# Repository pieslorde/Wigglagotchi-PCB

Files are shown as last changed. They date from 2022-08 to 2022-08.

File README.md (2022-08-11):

# Wigglagotchi-PCB
This repository contains the Altium Designer AD22 source files and generated Gerber, NC drill, and
documentation files for PCB of the Wigglagotchi. The enclosure for the device is maintained in
[Wigglagotchi-Mechanical](https://github.com/pieslorde/Wigglagotchi-Mechanical). The Wigglagotchi
is an open-source handheld gaming device with three buttons, a screen, an IMU, a buzzer, and an
IrDA transceiver to communicate with other Wigglagotchis.

The namesake of the Wigglagotchi is the Twitch streamer [Keffals](https://wikipedia.org/wiki/Keffals).
A frequent feature of her community is an [animated chibi-style version of herself
dancing](https://twitter.com/keffals/status/1509562415096213510), or wiggling. Chatters who use the emote are referred
to as "Wigglers", and the Wigglagotchi was designed to support virtual Wiggler pets for the user.

A document containing 3D renders of the assembled PCB, a BOM, and the schematic is
[included here](https://github.com/pieslorde/Wigglagotchi-PCB/blob/main/Project%20Outputs%20for%20Wigglagotchi/Documentation.PDF).

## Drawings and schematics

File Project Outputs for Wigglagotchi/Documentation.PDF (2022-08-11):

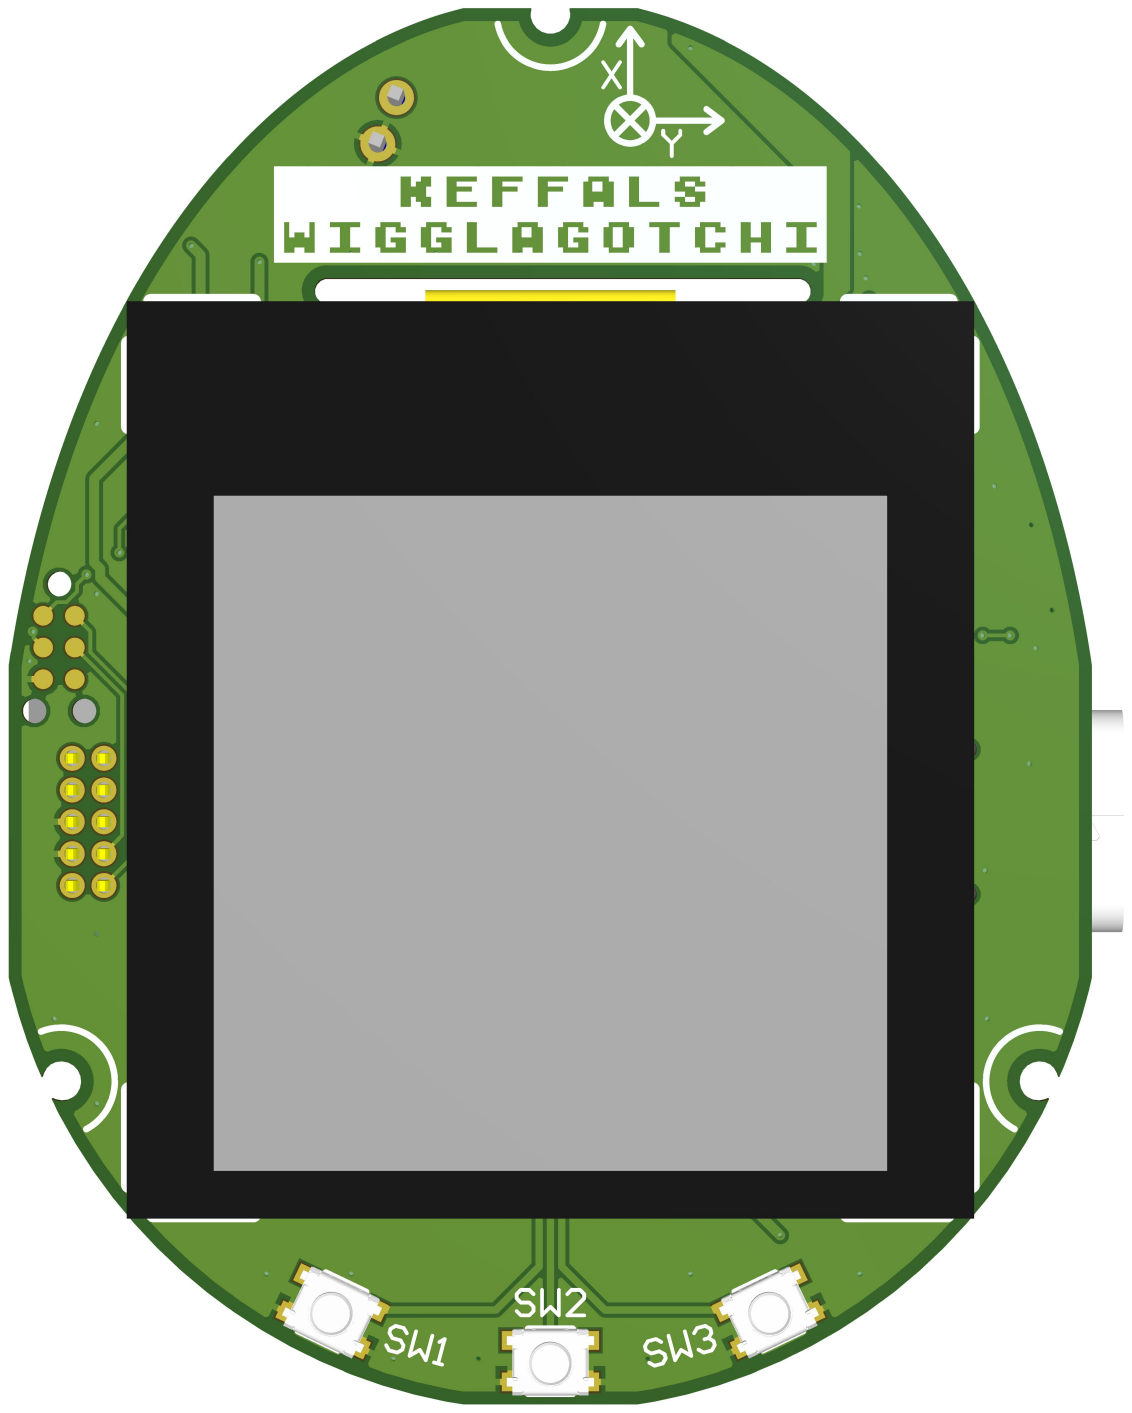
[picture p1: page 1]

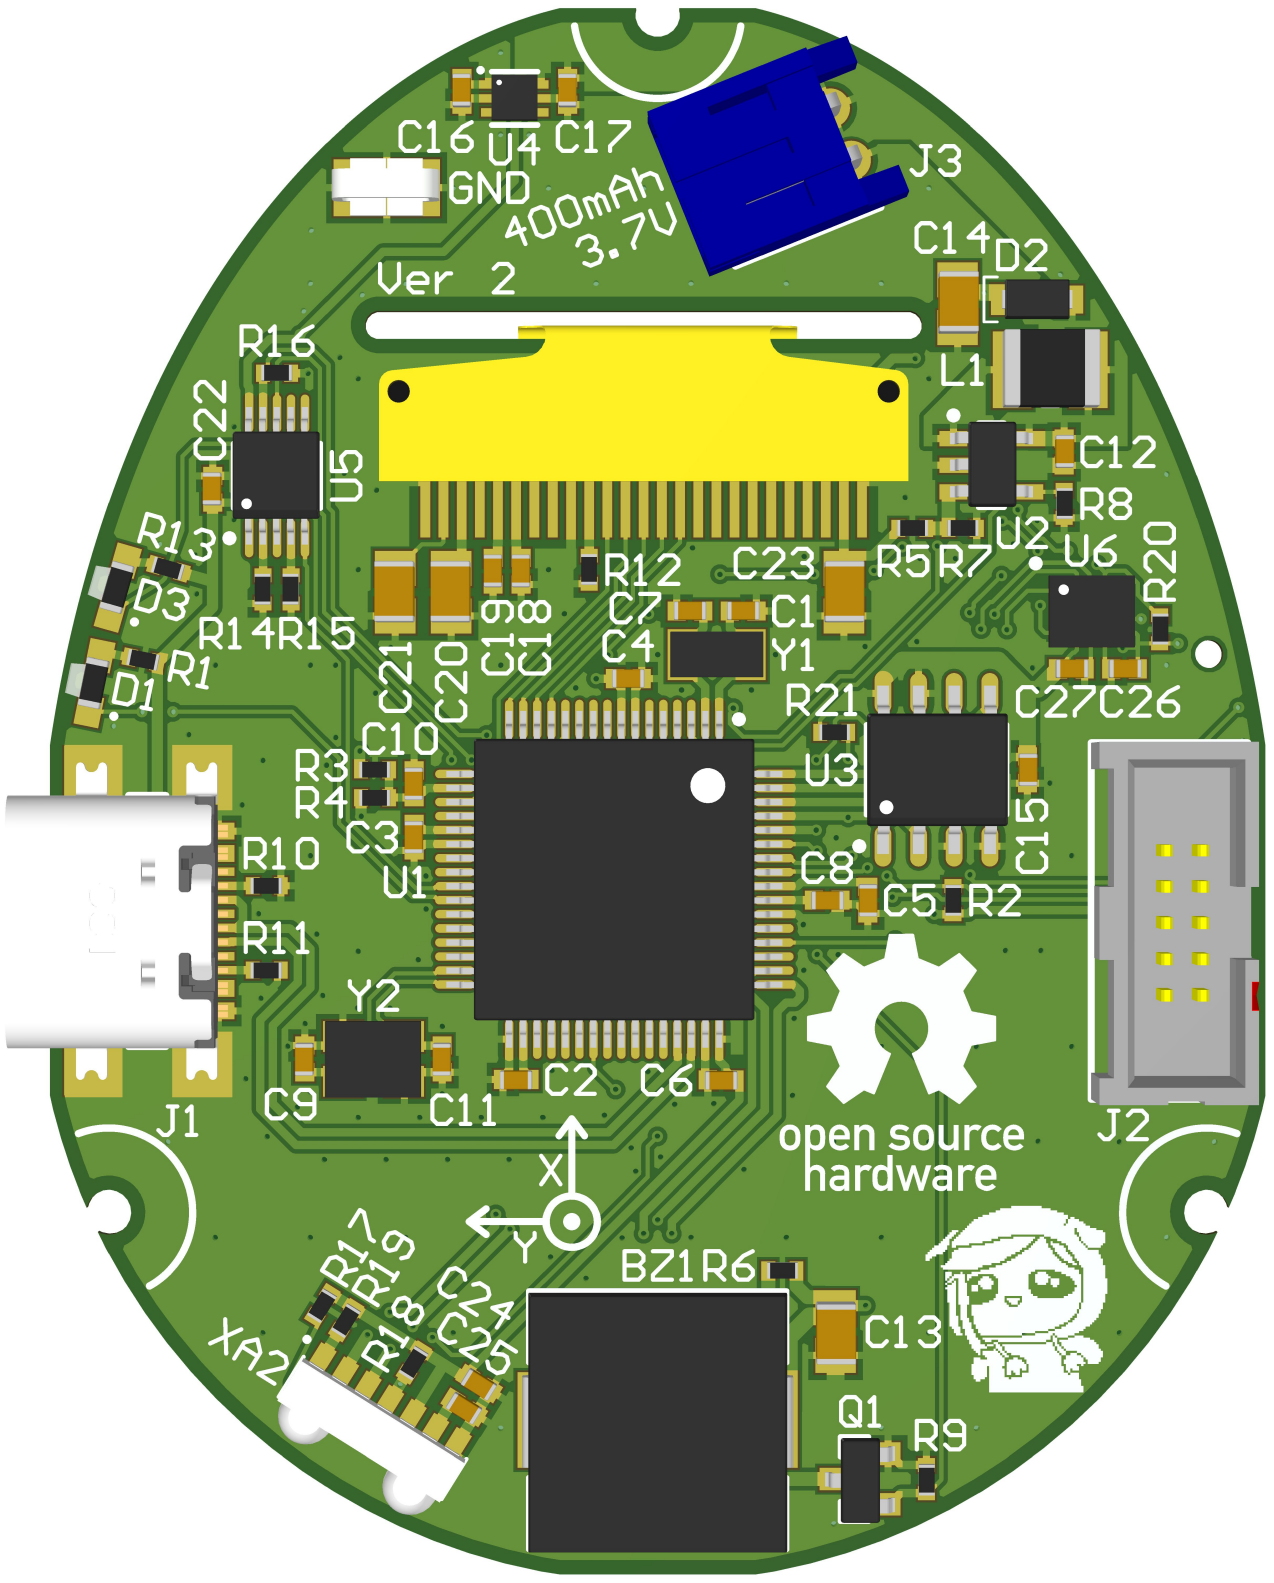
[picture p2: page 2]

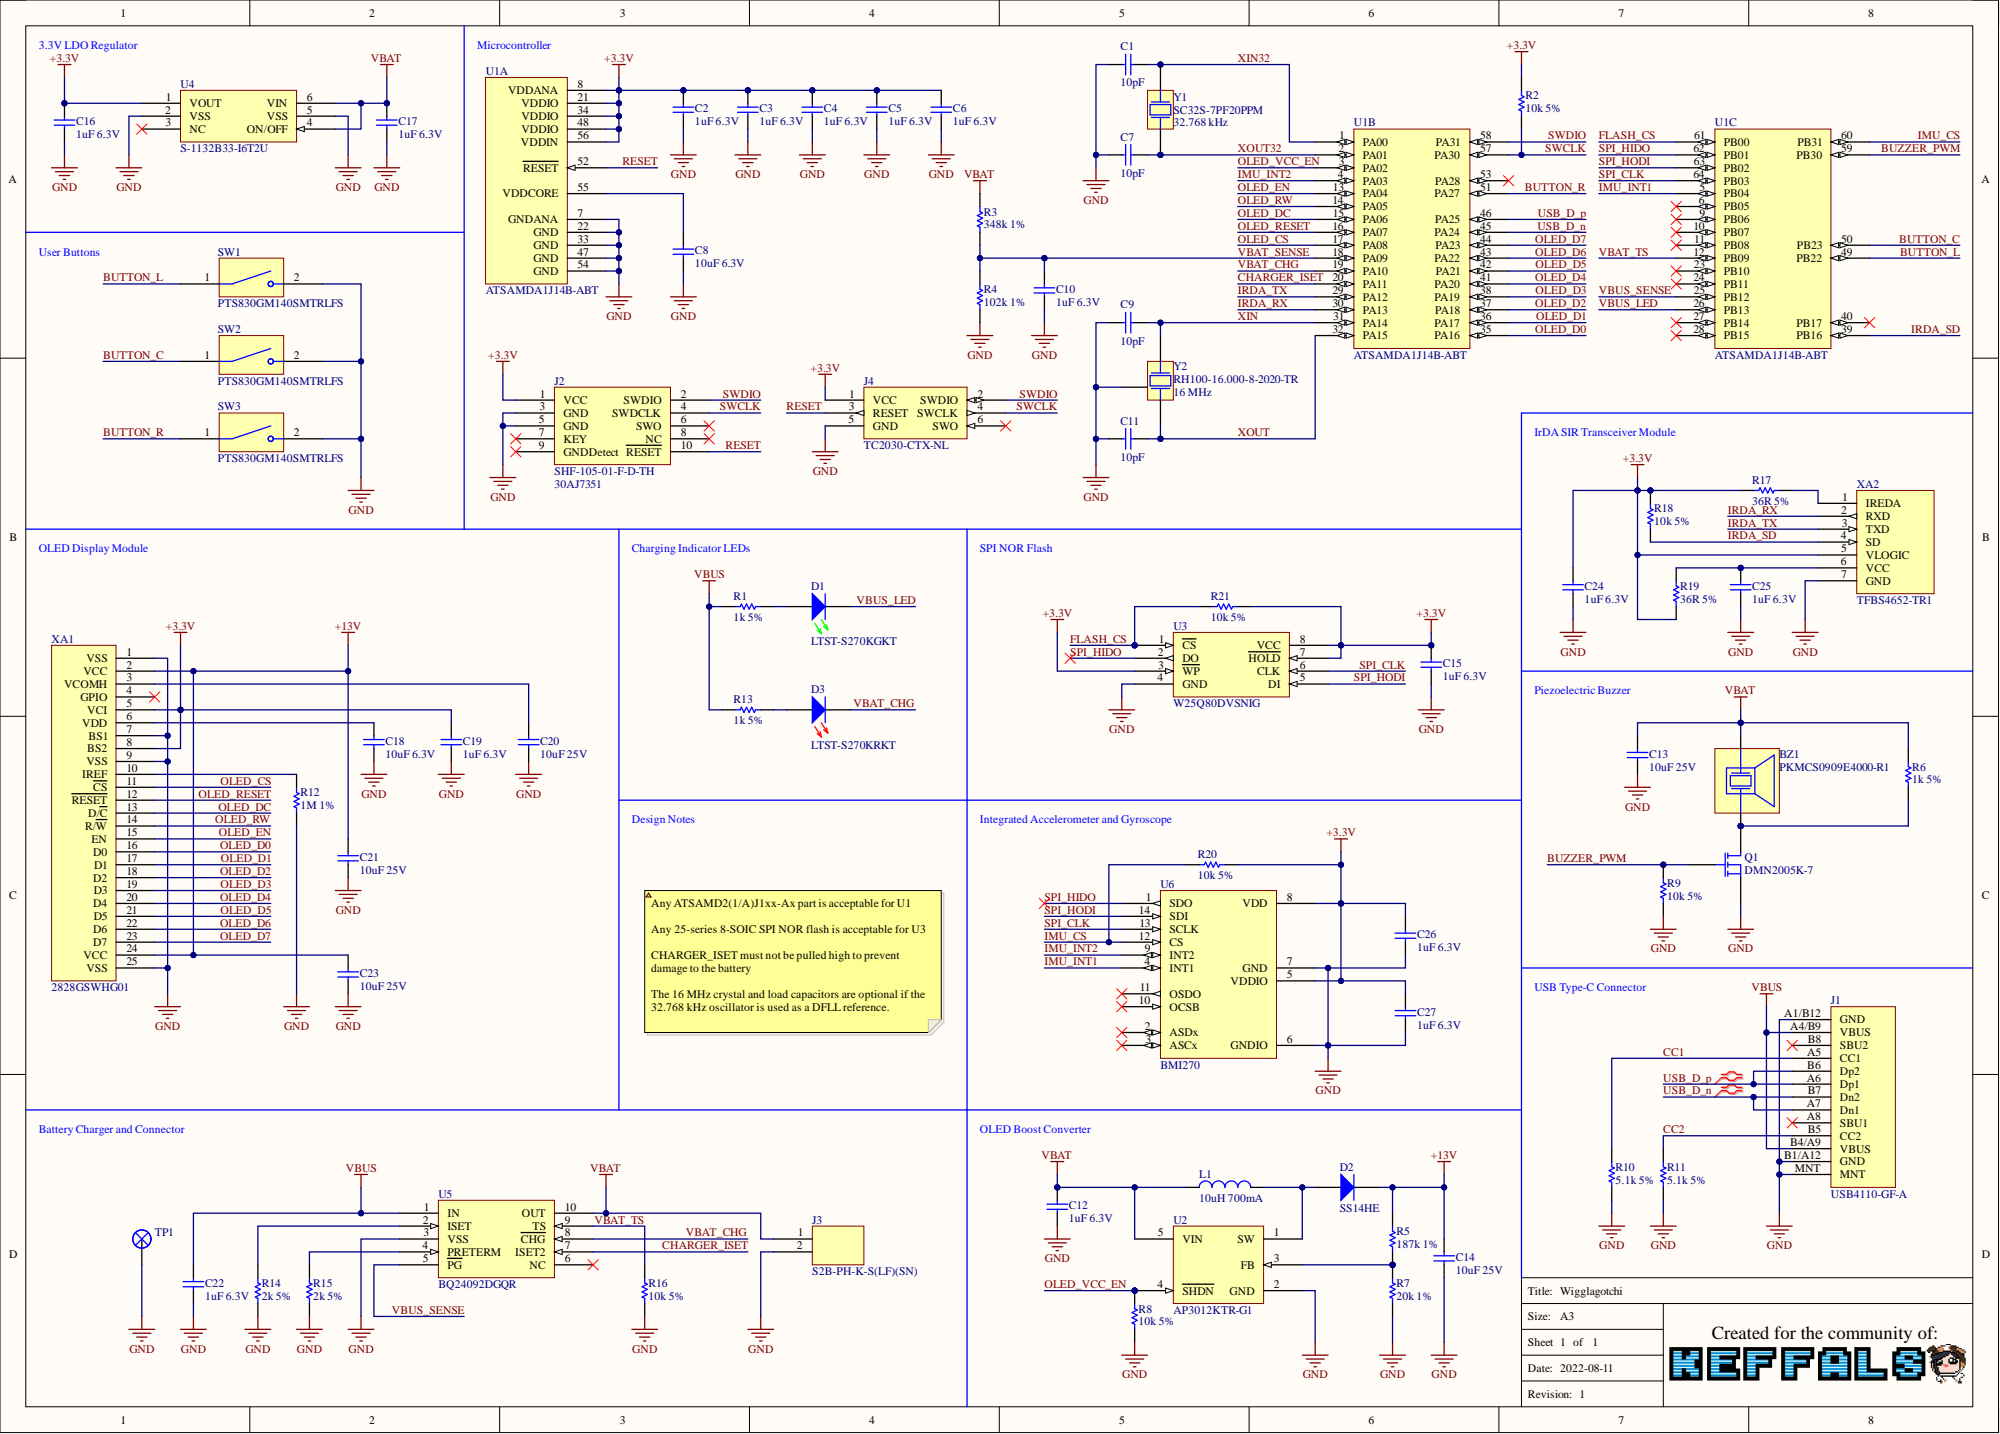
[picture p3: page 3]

IrDA SIR Transceiver Module

Integrated Accelerometer and Gyroscope

Any ATSAMD2(1/A)J1xx-Ax part is acceptable for U1

Any 25-series 8-SOIC SPI NOR flash is acceptable for U3

CHARGER_ISET must not be pulled high to prevent
damage to the battery

The 16 MHz crystal and load capacitors are optional if the
32.768 kHz oscillator is used as a DFLL reference.

SBU1 A8

VBUS B4/A9

Created for the community of:

Manufacturer 1 | Name | Designator | Quantity
Winbond | W25Q80DVSNIG | U3 | 1
Global Connector Technology | USB4110-GF-A | J1 | 1
Vishay Semiconductors | TFBS4652-TR1 | XA2 | 1
ON Semiconductor / Fairchild | SS14HE | D2 | 1
Samtec | SHF-105-01-F-D-TH | J2 | 1
Seiko | SC32S-7PF20PPM | Y1 | 1
ABLIC | S-1132B33-I6T2U | U4 | 1
JST | S2B-PH-K-S(LF)(SN) | J3 | 1
Stackpole Electronics | RMCF0402JT36R0 | R17, R19 | 2
Stackpole Electronics | RMCF0402JT10K0 | R2, R8, R9, R16, R18, R20, R21 | 7
Stackpole Electronics | RMCF0402JT5K10 | R10, R11 | 2
Stackpole Electronics | RMCF0402JT2K00 | R14, R15 | 2
Stackpole Electronics | RMCF0402JT1K00 | R1, R6, R13 | 3
Stackpole Electronics | RMCF0402FT348K | R3 | 1
Stackpole Electronics | RMCF0402FT187K | R5 | 1
Stackpole Electronics | RMCF0402FT102K | R4 | 1
Stackpole Electronics | RMCF0402FT20K0 | R7 | 1
Stackpole Electronics | RMCF0402FT1M00 | R12 | 1
Raltron Electronics | RH100-16.000-8-2020-TR | Y2 | 1
ITT C&K | PTS830GM140SMTRLFS | SW1-SW3 | 3
Murata | PKMCS0909E4000-R1 | BZ1 | 1
Vishay Lite-On | LTST-S270KRKT | D3 | 1
Vishay Lite-On | LTST-S270KGKT | D1 | 1
Murata | GRM155R60J106ME15D | C8, C18 | 2
Murata | GRM153R60J105ME15D | C2-C6, C10, C12, C15-C17, C19, C22, C24-C27 | 16
Murata | GRM21BR61E106KA73K | C13, C14, C20, C21, C23 | 5
Murata | GCM1555C1H100GA16D | C1, C7, C9, C11 | 4
Diodes Zetex | DMN2005K-7 | Q1 | 1
Taiyo Yuden | BRL3225T100K | L1 | 1
Texas Instruments | BQ24092DGQR | U5 | 1
Bosch Sensortec | BMI270 | U6 | 1
Microchip | ATSAMDA1J14B-ABT | U1 | 1
Diodes | AP3012KTR-G1 | U2 | 1
Keystone Electronics | 5019 | TP1 | 1

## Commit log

2022-08-11 Initial commit. Missing license information and readme
    [Wigglagotchi.PrjPcb, Wigglagotchi.SchDoc, footprints.PcbLib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]
2022-08-11 Forgot to add project outputs
    [Wigglagotchi.GBL, Wigglagotchi.GBO, Wigglagotchi.GBP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]
